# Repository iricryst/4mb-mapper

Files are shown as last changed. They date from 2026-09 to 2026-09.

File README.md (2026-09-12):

# Philips NMS8280 MSX2 4MB memory mapper

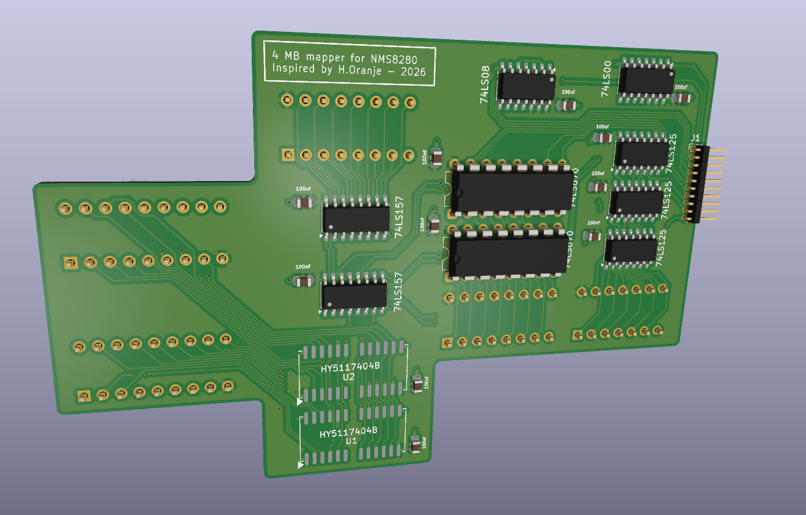
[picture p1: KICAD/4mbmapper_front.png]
4MB mapper PCB front


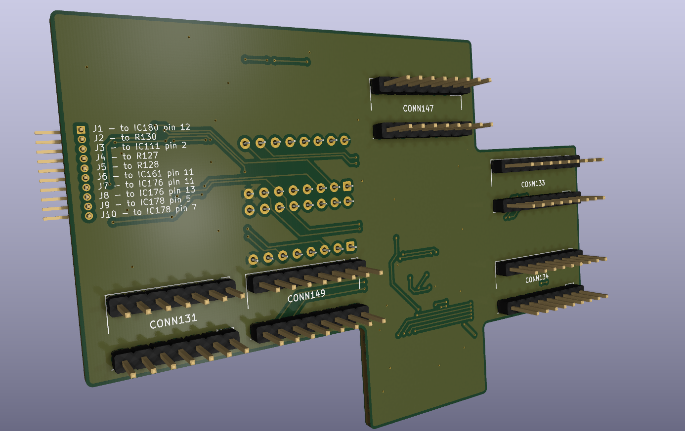
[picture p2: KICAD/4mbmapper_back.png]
4MB mapper PCB back


First and foremost:

> **WARNING:** Do not use or build this board until the correct measurements
> have been completed on the prototype. This design has not yet been verified
> for production use. A prototype has been ordered from JLCPCB. Precise measurements
> will be taken soon, mechanically as well as electrically.

In here you will find my PCB design, based on the original design by Hans Oranje. See reference documents below. 

My goal was to create a PCB to get rid of most of the wiring described in the original paper.

Why design yet another PCB, while there are so many other solutions? 

- This design replaces the stock memory, so it doesn't occupy a (expanded) slot. It just keeps the memory at slot 3.2
- No piggybacking IC's on the original IC's. The piggybacking still occurs, but neatly on the PCB
- No gazzilion wires, creating spaghetti
- Reverting back to stock should be easy
- Profile kept as low as possible to fit

## BOM

<a href="https://htmlpreview.github.io/?https://github.com/iricryst/4mb-mapper/blob/main/KICAD/bom/ibom.html" target="_blank" rel="noopener noreferrer">BOM</a>

<a href="./KICAD/bom/ibom.html" target="_blank" rel="noopener noreferrer">BOM</a>

## Alternative PCB version

The [`KICAD_670_DIP`](./KICAD_670_DIP/) folder contains a second version of the
PCB and schematic. It is intended for the DIP-package `74LS670` variant, which
is provided as an alternative because of market availability.

<a href="./KICAD_670_DIP/bom/ibom.html" target="_blank" rel="noopener noreferrer">DIP version BOM</a>

## Manual

wip

## Reference and documentation

- [Hans Oranje paper in Dutch](./DOC/4mbnms8280.pdf)
- [HY5117404B](./DOC/HY5117404B.pdf)
- [SN74LS00](./DOC/SN74LS00.pdf)
- [SN74LS08](./DOC/SN74LS08.pdf)
- [SN74LS125](./DOC/SN74LS125.pdf)
- [SN74LS157](./DOC/SN74LS157.pdf)
- [SN74LS670](./DOC/SN74LS670.pdf)

The RAM used by this design is HY5117404B, represented by the custom
`HYB5117400BJ` symbol in the schematic. The `1464` custom symbol has no
manufacturer part number in the schematic, so no unambiguous datasheet can be
assigned to it.

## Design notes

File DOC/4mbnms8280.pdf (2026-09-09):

### 4 MB PC-SIMM in NMS 8280

Benodigde onderdelen:

1 x 74LS670
2 x 74LS125
1 x 74LS08
1 x 74LS00
1 x 74LS157
1 x 4 MB 30 pin PC-SIMM

Verwijder IC 133 t/m IC 136 ( 41464 ) bij VDP.
Verwijder R 127 en R 128 ( beide 100 ohm ) in de buurt van IC 131 ( 74LS125).

Bereid de volgende IC’s voor.

74LS670 | : knip de pennen 1, 2, 3, 6, 7, 9, 10 en 15 half af.
74LS125(1) | : knip de pennen 2, 3, 5, 6, 8, 9, 11 t/m 13 half af.
74LS125(2) | : knip de pennen 2, 3, 5, 6, 8, 9, 11 t/m 12 half af.
74LS08 | : knip de pennen 1 t/m 6 en 8 t/m 13 half af.
74LS00 | : knip de pennen 1 t/m 6 en 8 t/m 13 half af.
74LS157 | : knip de pennen 2 t/m 7 en 9 t/m 14 half af.

Plaats de 74LS670 boven op IC 149 (74LS670) en heet vanaf nu IC 149B.
Plaats de 74LS125 boven op IC 131 (74LS125) en heet vanaf nu IC 131B.
Plaats de tweede 74LS125 boven op IC 131B (74LS125) en heet vanaf nu IC 131C. Plaats de 74LS08 boven op IC 157 (74LS00) en heet vanaf nu IC 157B.
Plaats de 74LS00 boven op IC 180 (74LS32) en heet vanaf nu IC 180B.
Plaats de 74LS157 boven op IC 147 (74LS157) en heet vanaf nu IC 147B. Soldeer alle overgebleven hele pennen van deze IC’s op de onderliggende IC’s

Breng een draadbrug aan op IC 131C (74LS125) tussen pen 13 en pen 1.

Breng een draadbrug aan op IC 157B (74LS08) tussen pen 14, pen 13 en pen 12. Breng een draadbrug aan op IC 157B (74LS08) tussen pen 11, pen 10 en pen 9.

Breng een draadbrug aan op IC 180B (74LS00) tussen pen 14, pen 13 en pen 12.
Breng een draadbrug aan op IC 180B (74LS00) tussen pen 11, pen 10 en pen 9.
Breng een draadbrug aan op IC 180B (74LS00) tussen pen 3 en pen 4.

Breng een draad aan tussen pen 12 IC 180 (74LS32) en pen 1 en 2 van IC 180B (74LS00) (RFSH). Breng een draad aan tussen R 130 ( 100 ohm) ( zijde Video RAM ) en pen 5 van IC 180B (74LS00) (WE).

Breng een draad aan tussen printspot R 128 ( zijde RAM) en pen 3 van IC 157B (74LS08) (CAS 0). Breng een draad aan tussen printspot R 127 ( zijde RAM) en pen 6 van IC 157B (74LS08) (CAS1). Breng een draad aan tussen pen 2 IC 111 (74LS32) naar pen 1 en 4 van IC157B (74LS08) (CAS2/E) Breng een draad aan tussen pen 2 en 5 van IC 157B (74LS08) naar pen 6 IC 180B (74LS00).

Breng een draad aan tussen pen 7 IC 149 (74LS670) en pen 2 IC 147B (74LS157) (MA16)

Breng een draad aan tussen pen 11 van IC 161 (74LS243) en pen 3 van IC 131B (74LS125) en pen 3 van IC 149 (74LS670) (D3).

Breng een draad aan tussen pen 2 van IC 131B (74LS125) en pen 6 van IC 149 (74LS670) en pen 3 van IC 147B (74LS157) (MA17).

Breng een draad aan tussen pen 15 van IC 149B (74LS670) en pen 6 van IC 131B (74LS125) en pen 11 van IC 176 (74LS367) (D4).

Breng een draad aan tussen pen 5 van IC 131B (74LS125) en pen 10 van IC 149B (74LS670) en pen 5 van IC 147B (74LS157) (MA18).

Breng een draad aan tussen pen 1 van IC 149B (74LS670) en pen 8 van IC 131B (74LS125) en pen 13 van IC 176 (74LS367) (D5).

Breng een draad aan tussen pen 9 van IC 131B (74LS125) en pen 9 van IC 149B (74LS670) en pen 6 van IC 147B (74LS157) (MA19).

Breng een draad aan tussen pen 2 van IC 149B (74LS670) en pen 11 van IC 131B (74LS125) en pen 5 van IC 178 (74LS367) (D6).

Breng een draad aan tussen pen 12 van IC 131B (74LS125) en pen 7 van IC 149B (74LS670) en pen 11 van IC 147B (74LS157) (MA20).

Breng een draad aan tussen pen 3 van IC 149B (74LS670) en pen 3 van IC 131C (74LS125) en pen 7 van IC 178 (74LS367) (D7).

Breng een draad aan tussen pen 2 van IC 131C (74LS125) en pen 6 van IC 149B (74LS670) en pen 10 van IC 147B (74LS157) (MA21).

Draai nu het moederbord om.
Knip alle IC pennen aan de onderkant tussen IC 147 en IC 176 glad af. Bevestig op dubbelzijdig plakband de PC-SIMM op deze locatie.

Bij de volgende omschrijving worden draden rechtstreeks gesoldeerd van PC-SIMM naar locatie c.q. printspot onderzijde IC en begin bij punt 1.
De 3 draden naar IC 147B ( 74LS157) gaan door een leeg gezogen IC gat.
pen | Omschrijving | locatie SIMM
30 | Vcc + 5 Volt | IC 133 pen 9
29 | Din(9)
28 | CAS(9)
27 | RAS | IC 133 pen 5
26 | Dout(9)
25 | D7 | IC 133 pen 17
24 | NC
23 | D6 | IC 133 pen 15
22 | Gnd | IC 133 pen 18
21 | WE | IC 133 pen 4
20 | D5 | IC 133 pen 3
19 | L10 | IC 147B pen 9 ( 74LS157)
18 | L9 | IC 147B pen 7 ( 74LS157)
17 | L8 | IC 147B pen 4 ( 74LS157)
16 | D4 | IC 133 pen 2
15 | L7 | IC 136 pen 10
14 | L6 | IC 136 pen 6
13 | D3 | IC 134 pen 17
12 | L5 | IC 136 pen 7
11 | L4 | IC 136 pen 8
10 | D2 | IC 134 pen 15
09 | Gnd | IC 134 pen 18
08 | L3 | IC 134 pen 11
07 | L2 | IC 134 pen 12
06 | D1 | IC 134 pen 3
05 | L1 | IC 134 pen 13
04 | L0 | IC 134 pen 14
03 | D0 | IC 134 pen 2
02 | CAS | IC 134 pen 16
01 | Vcc + 5 Volt | IC 134 pen 9

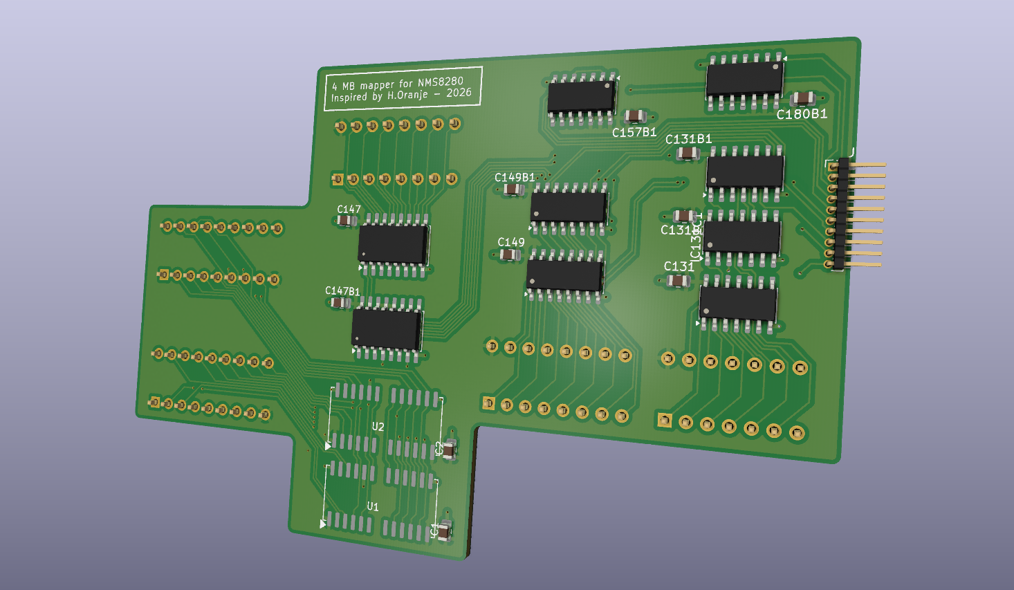
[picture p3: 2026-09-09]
KICAD_670_DIP/4mbmapper.png

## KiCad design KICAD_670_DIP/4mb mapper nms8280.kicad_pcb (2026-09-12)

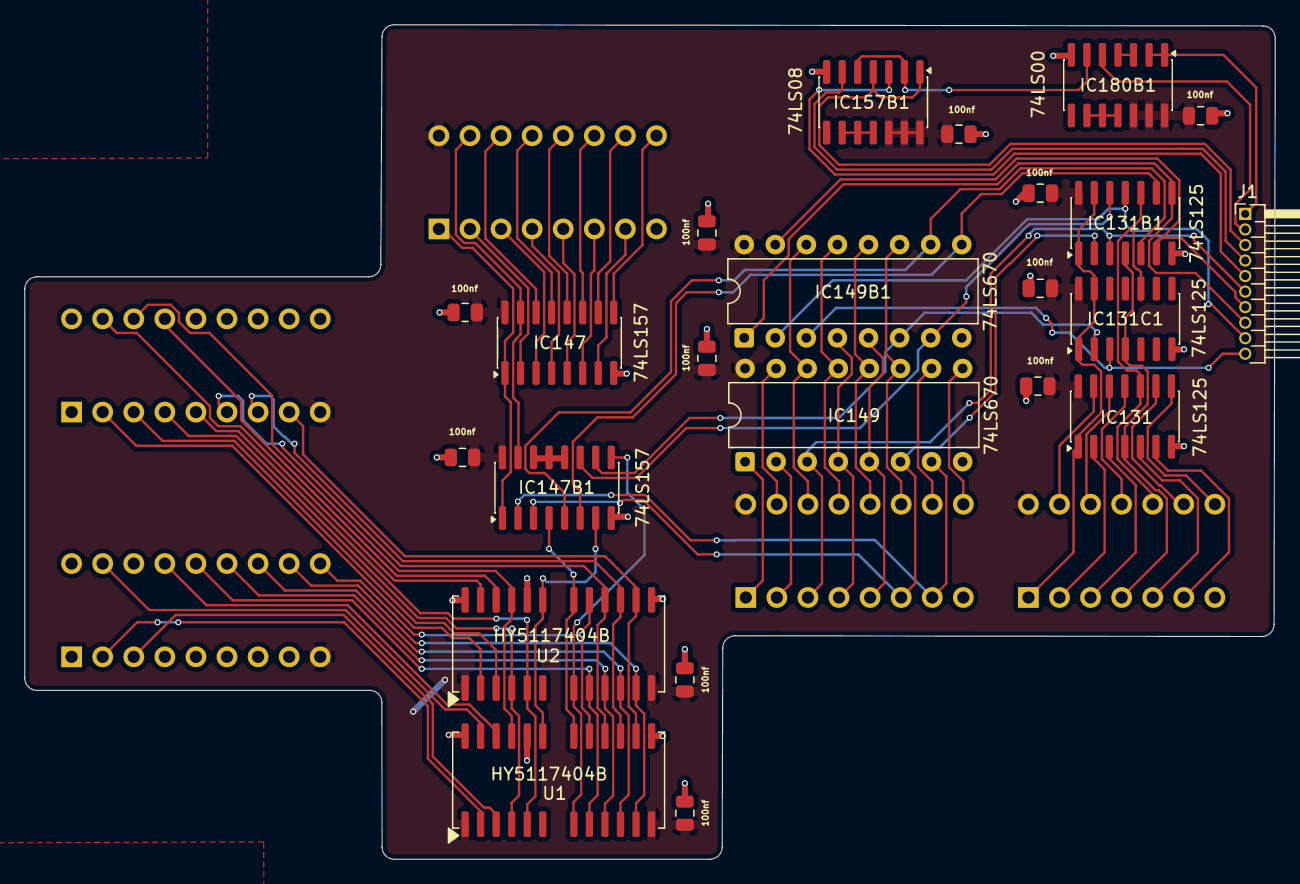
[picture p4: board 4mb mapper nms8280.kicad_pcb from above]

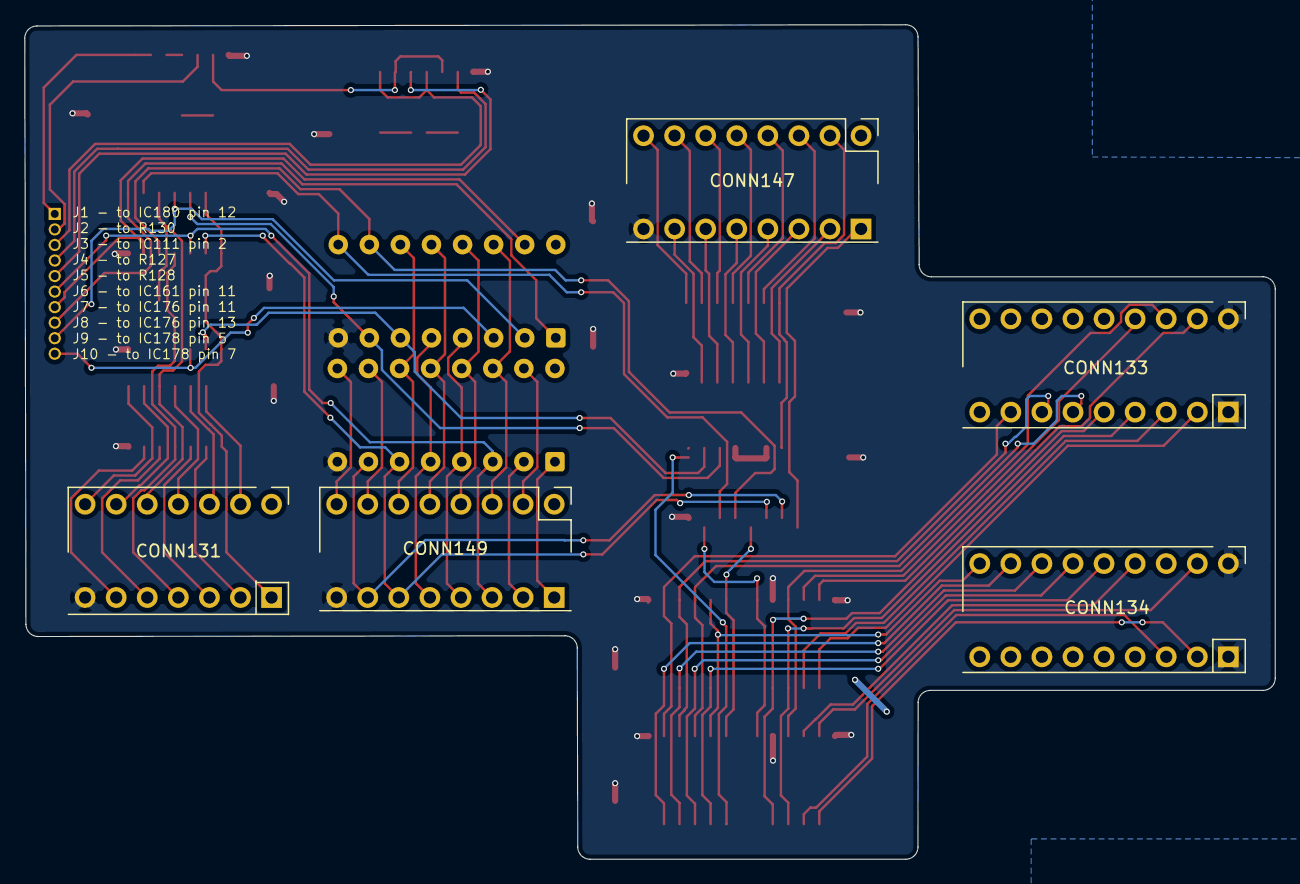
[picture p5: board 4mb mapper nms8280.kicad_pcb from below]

Board: 2 copper layers, 102.2 x 68.2 mm, 28 parts (5 on the bottom side), 82 nets.

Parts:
C1, C2, C131, C131B1, C131B2, C147, C147B1, C149, C149B1, C157B1, C180B1: 100nf; C_0805_2012Metric
CONN131: Pin Header 2x7 2,54mm Rounded; PinHeader_2x07_P2.54mm_Vertical
CONN133, CONN134: Pin Header 2x9 2,54mm Rounded; PinHeader_2x09_P2.54mm_Vertical
CONN147, CONN149: Pin Header 2x8 2,54mm Rounded; PinHeader_2x08_P2.54mm_Vertical
IC131, IC131B1, IC131C1: 74LS125; SOIC-14_3.9x8.7mm_P1.27mm
IC147, IC147B1: 74LS157; SOIC-16_3.9x9.9mm_P1.27mm
IC149, IC149B1: 74LS670; DIP-16_W7.62mm
IC157B1: 74LS08; SOIC-14_3.9x8.7mm_P1.27mm
IC180B1: 74LS00; SOIC-14_3.9x8.7mm_P1.27mm
J1: Conn_01x10_Pin; PinHeader_1x10_P1.27mm_Horizontal
U1, U2: HY5117404B; SOJ-2624_7.62x18.415mm_P1.27mm

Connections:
/4mb mapper nms8280/131b_131c_p13: CONN131.1 (1A), IC131.1 (1E), IC131B1.1 (1E), IC131B1.13 (4E), IC131C1.1 (1E), IC131C1.13 (4E)
/4mb mapper nms8280/<NO NET>: IC180B1.1 (1A), IC180B1.2 (1B), J1.1
/4mb mapper nms8280/IC131_P2: CONN131.2 (1B), IC131.2 (1D)
/4mb mapper nms8280/IC131_P3: CONN131.3 (1Y), IC131.3 (1O)
/4mb mapper nms8280/IC131_P4_IC131B: CONN131.4 (2A), IC131.4 (2E), IC131B1.4 (2E), IC131C1.4 (2E)
/4mb mapper nms8280/IC131_P5: CONN131.5 (2B), IC131.5 (2D)
/4mb mapper nms8280/IC131_P6: CONN131.6 (2Y), IC131.6 (2O)
/4mb mapper nms8280/IC131_P8: CONN131.8 (3Y), IC131.8 (3O)
/4mb mapper nms8280/IC131_P9: CONN131.9 (3A), IC131.9 (3D)
/4mb mapper nms8280/IC131_P10_IC131B: CONN131.10 (3B), IC131.10 (3E), IC131B1.10 (3E), IC131C1.10 (3E)
/4mb mapper nms8280/IC131_P11: CONN131.11 (4Y), IC131.11 (4O)
/4mb mapper nms8280/IC131_P12: CONN131.12 (4A), IC131.12 (4D)
/4mb mapper nms8280/IC131_P13: CONN131.13 (4B), IC131.13 (4E)
/4mb mapper nms8280/IC147_P1_IC147B: CONN147.1 (S), IC147.1 (S), IC147B1.1 (S)
/4mb mapper nms8280/IC147_P2: CONN147.2 (A0), IC147.2 (I0a)
/4mb mapper nms8280/IC147_P3: CONN147.3 (B0), IC147.3 (I1a)
/4mb mapper nms8280/IC147_P4: CONN147.4 (Y0), IC147.4 (Za)
/4mb mapper nms8280/IC147_P5: CONN147.5 (A1), IC147.5 (I0b)
/4mb mapper nms8280/IC147_P6: CONN147.6 (B1), IC147.6 (I1b)
/4mb mapper nms8280/IC147_P7: CONN147.7 (Y1), IC147.7 (Zb)
/4mb mapper nms8280/IC147_P9: CONN147.9 (Y2), IC147.9 (Zc)
/4mb mapper nms8280/IC147_P10: CONN147.10 (B2), IC147.10 (I1c)
/4mb mapper nms8280/IC147_P11: CONN147.11 (A2), IC147.11 (I0c)
/4mb mapper nms8280/IC147_P12: CONN147.12 (Y3), IC147.12 (Zd)
/4mb mapper nms8280/IC147_P13: CONN147.13 (B3), IC147.13 (I1d)
/4mb mapper nms8280/IC147_P14: CONN147.14 (A3), IC147.14 (I0d)
/4mb mapper nms8280/IC147_P15_IC147B: CONN147.15 (E), IC147.15 (E), IC147B1.15 (E)
/4mb mapper nms8280/IC149_P1: CONN149.1 (D2), IC149.1 (D2)
/4mb mapper nms8280/IC149_P2: CONN149.2 (D3), IC149.2 (D3)
/4mb mapper nms8280/IC149_P3: CONN149.3 (D4), IC131B1.3 (1O), IC149.3 (D4), J1.6
/4mb mapper nms8280/IC149_P4_IC149B: CONN149.4 (RB), IC149.4 (Rb), IC149B1.4 (Rb)
/4mb mapper nms8280/IC149_P5_IC149B: CONN149.5 (RA), IC149.5 (Ra), IC149B1.5 (Ra)
/4mb mapper nms8280/IC149_P6: CONN149.6 (Q4), IC131B1.2 (1D), IC147B1.3 (I1a), IC149.6 (Q4)
/4mb mapper nms8280/IC149_P7: CONN149.7 (Q3), IC147B1.2 (I0a), IC149.7 (Q3)
/4mb mapper nms8280/IC149_P9: CONN149.9 (Q2), IC149.9 (Q2)
/4mb mapper nms8280/IC149_P10: CONN149.10 (Q1), IC149.10 (Q1)
/4mb mapper nms8280/IC149_P11_IC149B: CONN149.11 (ER), IC149.11 (~Er), IC149B1.11 (~Er)
/4mb mapper nms8280/IC149_P12_IC149B: CONN149.12 (EW), IC149.12 (~Ew), IC149B1.12 (~Ew)
/4mb mapper nms8280/IC149_P13_IC149B: CONN149.13 (WB), IC149.13 (Wb), IC149B1.13 (Wb)
/4mb mapper nms8280/IC149_P14_IC149B: CONN149.14 (WA), IC149.14 (Wa), IC149B1.14 (Wa)
/4mb mapper nms8280/IC149_P15: CONN149.15 (D1), IC149.15 (D1)
/ram section/A0_IC133/134_P14: CONN134.14 (A0), U1.9 (A0), U2.9 (A0)
/ram section/A1_IC133/134_P13: CONN134.13 (A1), U1.10 (A1), U2.10 (A1)
/ram section/A2_IC133/134_P12: CONN134.12 (A2), U1.11 (A2), U2.11 (A2)
/ram section/A3_IC133/134_P11: CONN134.11 (A3), U1.12 (A3), U2.12 (A3)
/ram section/A4_IC133/134_P8: CONN133.8 (A4), U1.15 (A4), U2.15 (A4)
/ram section/A5_IC133/134_P7: CONN133.7 (A5), U1.16 (A5), U2.16 (A5)
/ram section/A6_IC133/134_P6: CONN133.6 (A6), U1.17 (A6), U2.17 (A6)
/ram section/A7_IC133/134_P10: CONN134.10 (A7), U1.18 (A7), U2.18 (A7)
/ram section/CAS_IC133/134_P16: CONN133.16 (CAS), U1.23 (CAS), U2.23 (CAS)
/ram section/D0_IC134_P2: CONN134.2 (D0), U1.2 (D0)
/ram section/D1_IC134_P3: CONN134.3 (D1), U1.3 (D1)
/ram section/D2_IC134_P15: CONN134.15 (D2), U1.24 (D2)
/ram section/D3_IC134_P17: CONN134.17 (D3), U1.25 (D3)
/ram section/D4_IC133_P2: CONN133.2 (D0), U2.2 (D0)
/ram section/D5_IC133_P3: CONN133.3 (D1), U2.3 (D1)
/ram section/D6_IC133_P15: CONN133.15 (D2), U2.24 (D2)
/ram section/D7_IC133_P17: CONN133.17 (D3), U2.25 (D3)
/ram section/RAS_IC133_P5: CONN133.5 (RAS), U1.5 (RAS), U2.5 (RAS)
/ram section/WE_IC133_P4: CONN133.4 (WE), U1.4 (WE), U2.4 (WE)
A8_IC147B_P4: IC147B1.4 (Za), U1.19 (A8), U2.19 (A8)
A9_IC147B_P7: IC147B1.7 (Zb), U1.21 (A9), U2.21 (A9)
A10_IC147B_P7: IC147B1.9 (Zc), U1.8 (A10), U2.8 (A10)
GND: C1.2, C2.2, C131.2, C131B1.2, C131B2.2, C147.1, C147B1.1, C149.2, C149B1.2, C157B1.1, C180B1.1, CONN131.7 (GND), CONN133.1 (OE), CONN133.18 (GND), CONN134.1 (OE), CONN134.18 (GND), CONN147.8 (GND), CONN149.8 (GND), IC131.7 (GND), IC131B1.7 (GND), IC131C1.7 (GND), IC147.8 (GND), IC147B1.8 (GND), IC149.8 (GND), IC149B1.8 (GND), IC157B1.7 (GND), IC180B1.7 (GND), U1.14 (GND), U1.22 (OE), U1.26 (GND), U2.14 (GND), U2.22 (OE), U2.26 (GND)
unnamed: IC131B1.5 (2D), IC147B1.5 (I0b), IC149B1.10 (Q1)
unnamed: IC131B1.6 (2O), IC149B1.15 (D1), J1.7
unnamed: IC131B1.9 (3D), IC147B1.6 (I1b), IC149B1.9 (Q2)
unnamed: IC131B1.8 (3O), IC149B1.1 (D2), J1.8
unnamed: IC131B1.12 (4D), IC147B1.11 (I0c), IC149B1.7 (Q3)
unnamed: IC131B1.11 (4O), IC149B1.2 (D3), J1.9
unnamed: IC131C1.2 (1D), IC147B1.10 (I1c), IC149B1.6 (Q4)
unnamed: IC131C1.3 (1O), IC149B1.3 (D4), J1.10
unnamed: IC147B1.12 (Zd), IC147B1.13 (I1d), IC147B1.14 (I0d)
unnamed: IC157B1.1 (1A), IC157B1.4 (2A), J1.3
unnamed: IC157B1.2 (1B), IC157B1.5 (2B), IC180B1.6 (2Y)
unnamed: IC157B1.3 (1Y), J1.5
unnamed: IC157B1.6 (2Y), J1.4
unnamed: IC157B1.9 (3A), IC157B1.10 (3B), IC157B1.11 (4Y)
unnamed: IC180B1.3 (1Y), IC180B1.4 (2A)
unnamed: IC180B1.5 (2B), J1.2
unnamed: IC180B1.9 (3A), IC180B1.10 (3B), IC180B1.11 (4Y)
Vcc: C1.1, C2.1, C131.1, C131B1.1, C131B2.1, C147.2, C147B1.2, C149.1, C149B1.1, C157B1.2, C180B1.2, CONN131.14 (Vcc), CONN133.9 (Vcc), CONN134.9 (Vcc), CONN147.16 (Vcc), CONN149.16 (Vcc), IC131.14 (Vcc), IC131B1.14 (Vcc), IC131C1.14 (Vcc), IC147.16 (VCC), IC147B1.16 (VCC), IC149.16 (VCC), IC149B1.16 (VCC), IC157B1.12 (4A), IC157B1.13 (4B), IC157B1.14 (Vcc), IC180B1.12 (4A), IC180B1.13 (4B), IC180B1.14 (Vcc), U1.1 (Vcc), U1.13 (Vcc), U2.1 (Vcc), U2.13 (Vcc)

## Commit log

2026-09-09 Initial 4MB mapper project
    [4mb mapper nms8280.kicad_pcb, 4mb mapper nms8280.kicad_sch, ram_section.kicad_sch]
2026-09-09 Update 4MB mapper PCB
    [4mb mapper nms8280.kicad_pcb]
2026-09-11 Update 4MB mapper design outputs
    [4mb mapper nms8280-B_Cu.gbr, 4mb mapper nms8280-B_Mask.gbr, 4mb mapper nms8280-B_Paste.gbr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]
2026-09-11 Remove Bill of Materials section from README
    Removed the Bill of Materials section and its link from the README.
2026-09-11 Organize KiCad files and documentation
    [4mb mapper nms8280-B_Cu.gbr, 4mb mapper nms8280-B_Mask.gbr, 4mb mapper nms8280-B_Paste.gbr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]
2026-09-11 Update IC147 footprints to SOIC-16
    [4mb mapper nms8280.kicad_pcb, 4mb mapper nms8280.kicad_sch]
2026-09-11 Update component values and BOM
    [4mb mapper nms8280.kicad_pcb, ram_section.kicad_sch]
2026-09-11 Add 74LS670 DIP PCB variant
    [4mb mapper nms8280.kicad_pcb, 4mb mapper nms8280.kicad_sch, ram_section.kicad_sch]
2026-09-11 Update 74LS670 DIP BOM
2026-09-11 Update README with BOM links
    Added a link to the BOM in the README file.
2026-09-11 Fix BOM link in README.md
    Updated BOM link to correct the URL format.
2026-09-12 Update 670 DIP PCB silkscreen and photos
    [4mb mapper nms8280.kicad_pcb]
